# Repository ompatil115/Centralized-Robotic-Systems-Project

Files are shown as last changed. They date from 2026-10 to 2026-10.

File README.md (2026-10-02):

# Centralized Robotic Systems

Centralized Robotic Systems is a personal engineering project that explores how multiple robotic devices can be monitored and controlled through a unified, browser-based interface.

The project is being developed incrementally. Each phase introduces a new robotic device or system capability while building toward centralized coordination across devices with different hardware, functions, and levels of complexity.

## Project Status

| Phase | Device or Capability | Status |
|---|---|---|
| Phase 1 | Embedded robotic vehicle | Complete (V1 scope) |
| Phase 2 | Additional robotic device (TBD) | Concept exploration |
| Future | Unified multi-device interface | Planned |

At present, the repository contains the completed Phase 1 robotic vehicle. Multi-device coordination has not been implemented yet.

## Phase 1: Embedded Robotic Vehicle Control System

Phase 1 demonstrates end-to-end remote control and two-way data communication between a browser interface and physical robotic hardware.

The vehicle has three primary functions:

1. Controllable multicolor lighting.
2. Forward, reverse, left, and right movement.
3. Distance scanning across a 180-degree field of view.

A browser-based interface accessible from devices on the same local network sends commands to the vehicle and displays returned sensor data.

### System Architecture

The system is divided into three primary layers:

- **Browser interface:** Provides lighting, movement, and scanning controls and displays scan results.
- **Raspberry Pi backend:** Hosts the Python/Flask service, processes HTTP requests, manages system state, and communicates with the Arduino through USB serial.
- **Arduino firmware:** Performs low-level control of the motors, servo, ultrasonic sensor, and lighting hardware.

This separation keeps the microcontroller firmware focused on hardware control while assigning interface and coordination functions to the Raspberry Pi.

### Communication Flow

```text
Browser Interface
       |
     HTTP
       |
Raspberry Pi 5
Python / Flask
       |
   USB Serial
       |
 Arduino Uno
       |
Motors, Servo, Ultrasonic Sensor, and Lighting
```

See [`Robot-Car-V1/`](Robot-Car-V1/) for full build documentation, firmware, backend code, and media.

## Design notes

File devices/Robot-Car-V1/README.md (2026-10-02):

# Embedded Robotic Vehicle Control System (Robot Car V1)

A browser-controlled robotic vehicle built on a Raspberry Pi and Arduino, 
supporting remote-controlled movement, RGB lighting, and ultrasonic distance 
scanning over a local network. Built as a first full-stack embedded systems 
project, from protocol design through firmware, backend, and interface.

## Overview

- **Firmware (C++, Arduino Uno)** — motor, servo, and ultrasonic sensor control
- **Backend (Python/Flask, Raspberry Pi)** — serial-to-HTTP bridge, 
  multithreaded command handling, safety watchdog
- **Interface (HTML/CSS/JS)** — browser-based control panel: color picker, 
  directional movement pad, and a live scan visualization

See [`docs/architecture.md`](docs/architecture.md) for system design and 
[`docs/protocol.md`](docs/protocol.md) for the full serial command spec.

## Features

- Real-time RGB lighting control via a gradient slider
- Directional drive/turn control with variable-speed forward movement
- 180° ultrasonic distance scanning with live results display
- Thread-safe backend handling concurrent serial I/O and command locking
- Motor safety watchdog that halts output if control input stops

## Hardware

- Raspberry Pi 5 (headless, Linux)
- Arduino Uno R3
- DRV8833 dual motor driver
- 2x 6V DC motors
- SG90 micro servo
- HC-SR04 ultrasonic sensor
- RGB LED

## Setup

**Firmware**
1. Open `firmware/robot_control.ino` in the Arduino IDE
2. Install the `Servo` and `SR04` libraries
3. Upload to an Arduino Uno wired per the pin map in `docs/architecture.md`

**Backend**
```bash
cd backend
pip install -r requirements.txt
python3 app.py
```
Connect the Arduino to the Pi via USB, then visit `http://<pi-ip>:5000` 
from any device on the same network.

## Status

Version 1 is complete and functional: all three subsystems (light, move, 
scan) work end-to-end, browser to hardware and back. V1 ran against a 
hardware constraint — attaching the servo library consumes a timer the 
Uno needs for PWM on two pins, leaving too few PWM-capable pins for full 
RGB and full variable-speed control in both directions. See 
`docs/architecture.md` for the tradeoff and what V1 scoped out as a result.

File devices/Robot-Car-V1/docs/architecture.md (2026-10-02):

# System Architecture

Three layers, each responsible for a distinct part of the system:

**Browser (JavaScript)** — renders the interface (light slider, movement pad, 
scan button/chart), computes derived values (RGB from slider position, 
direction/intensity from pad position), and sends commands to the backend 
over HTTP.

**Backend (Python/Flask, on Raspberry Pi)** — mediates between browser and 
hardware. Translates HTTP requests into serial commands, and parses serial 
responses back into JSON for the browser. Runs three concurrent threads: 
the main Flask request handler, a background serial reader (continuously 
parsing scan data and watching for completion), and a watchdog that halts 
motor output if movement commands stop arriving.

**Firmware (C++, on Arduino Uno)** — executes hardware control: PWM for 
motors and lighting, servo positioning, ultrasonic distance sampling. Parses 
incoming serial commands and dispatches to the matching function.

Computation was deliberately kept off the Arduino where possible (color 
math, direction/intensity logic) to minimize firmware complexity, since the 
Uno also handles time-sensitive sensor timing and motor control.

## Data flow
Browser → HTTP → Flask → Serial → Arduino → (physical action, or serial 
response) → Flask (background thread) → JSON → Browser

## V1 Hardware Constraint: PWM Pin Availability

The Arduino Uno has six PWM-capable pins. Attaching the Servo library 
claims Timer1, which disables PWM on two of them, leaving four usable 
PWM pins. Full-scope control (variable-speed in all four directions, 
plus full RGB) requires seven. V1 scoped down accordingly:

- **Light:** blue channel omitted entirely (saves one PWM pin); red and 
  green retain full gradient control.
- **Move:** only forward drive retains true variable speed (one PWM pin, 
  shared across both motors); backward and turning are binary — any 
  nonzero input runs at max intensity, since those directions use the 
  non-PWM motor pins.

This is a scoping decision, not a bug. Planned Version 2 fix: add a PCA9685 
PWM driver board, which provides 16 additional PWM channels, removing 
this constraint entirely.

## Physical Build

V1 used LEGO for the chassis, a deliberate rapid-prototyping choice to 
validate the electrical and software architecture without investing time 
in a custom frame before the control system was proven. Despite the 
material, the chassis followed real mechanical reasoning: a modular 
design (motors, battery, sensor/servo, and "brain" as separable units) 
for easy disassembly during debugging, with the battery — the heaviest 
component — placed directly over the wheel modules to minimize torque 
load during turns. Phase 2 replaces this with a soldered, purpose-built 
frame.

## Media

- **Full system demo (browser control → robot response):** https://youtu.be/HuvUpwN8BuI
- **Modular design:** https://youtu.be/toOqbU9Gd-k
- **Modular design breakdown:** https://youtu.be/CyCH8XhwyrI
- **Physical build:** [`media/robot-photo.jpg`](media/robot-photo.jpg)
- **Schematic:** [`media/schematic.png`](media/schematic.png) 
  ([KiCad source](media/robot-car.kicad_sch))

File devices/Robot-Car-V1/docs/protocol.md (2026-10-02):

# Serial Command Protocol

Communication between the Flask backend and Arduino firmware uses plain-text 
commands over USB serial, one command per line, terminated with `\n`.

## Light
- `LIGHT:<r>,<g>,0` — sets red/green PWM values (0–255). Blue omitted in V1 
  due to PWM pin constraints.
- `LIGHT:0` — turns the light off.

## Move
- `DRIVE:<i>` — forward/backward, intensity -100 to 100. Forward has true 
  variable speed; backward is binary (any negative value = max intensity).
- `TURN:<i>` — left/right, intensity -100 to 100, binary (any nonzero value 
  = max intensity).
- `DRIVE:0` / `TURN:0` — stop, halts all motor output regardless of axis.

Move commands are sent continuously (10–20 Hz) while an input is active. A 
backend watchdog sends a stop command if updates stop arriving.

## Scan
- `SCAN` — triggers a 0–180° servo sweep with ultrasonic distance sampling.
- `SCAN_DATA:<angle>:<distance>` — one line per reading, sent by the Arduino 
  during the sweep (distance in cm, 0–400).
- `SCAN_DONE` — sent once the sweep completes; the backend returns all 
  collected readings to the browser as JSON.

Only one command type (Light, Move, Scan) executes at a time. The backend 
rejects Light/Move requests while a scan is in progress.

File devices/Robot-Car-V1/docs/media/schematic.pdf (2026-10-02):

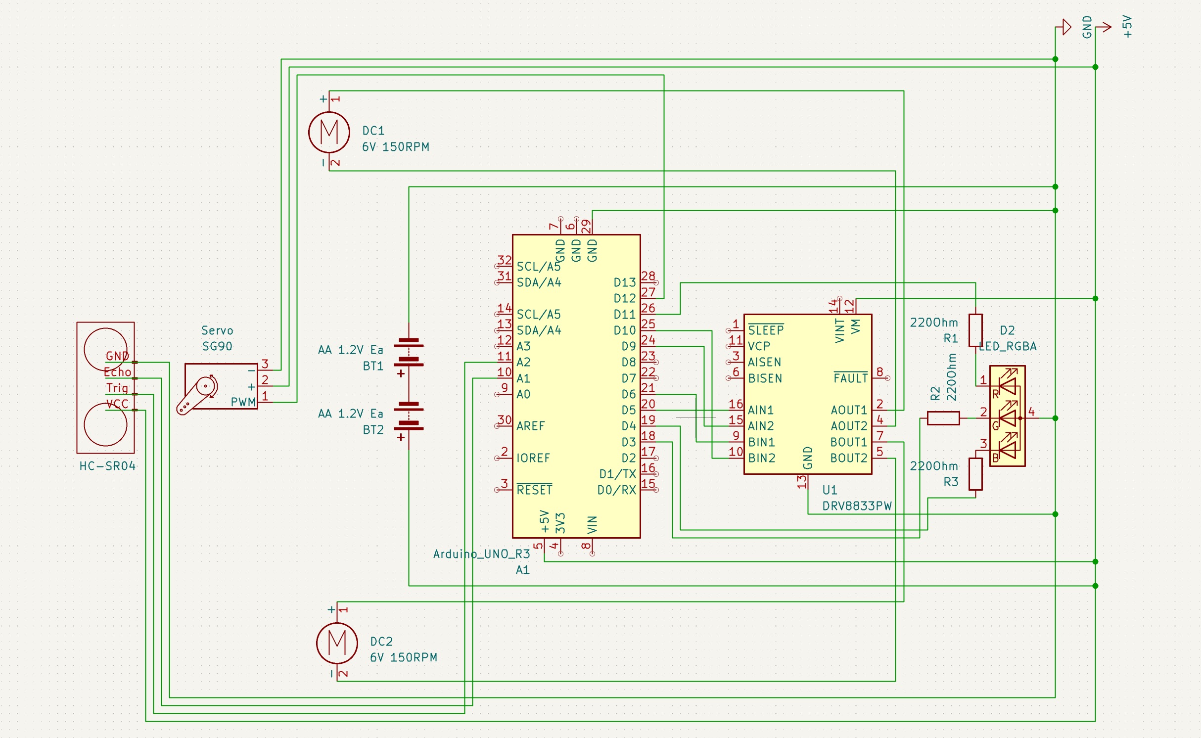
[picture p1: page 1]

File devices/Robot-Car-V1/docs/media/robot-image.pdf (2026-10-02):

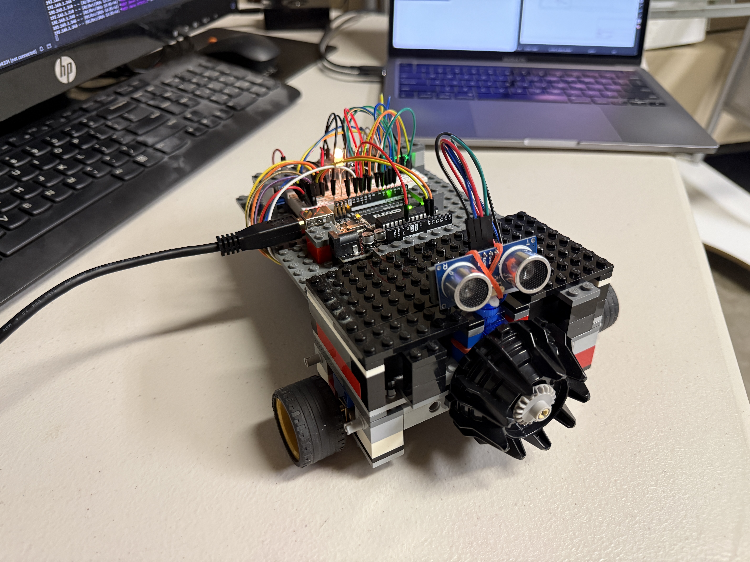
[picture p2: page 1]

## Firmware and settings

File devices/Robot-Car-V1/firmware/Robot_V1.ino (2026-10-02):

//  Robot V1 Code  //
//  Om Patil       //
//  2026-09-29     //

#include <Servo.h>
#include <SR04.h>

// ---------- Pin Definitions ----------
#define ENABLE 7
#define DIRA 5
#define DIRB 9
#define DIRC 6
#define DIRD 10
#define RED 11
#define GREEN 3
//#define BLUE 4
#define SERVO 12
#define TRIG_PIN A1
#define ECHO_PIN A0

Servo servo;
SR04 sr04(ECHO_PIN, TRIG_PIN);

void setup() {
  pinMode(ENABLE, OUTPUT);
  pinMode(DIRA, OUTPUT);
  pinMode(DIRB, OUTPUT);
  pinMode(DIRC, OUTPUT);
  pinMode(DIRD, OUTPUT);
  pinMode(RED, OUTPUT);
  pinMode(GREEN, OUTPUT);
  pinMode(TRIG_PIN, OUTPUT);
  pinMode(ECHO_PIN, INPUT);
  servo.attach(SERVO);
  digitalWrite(ENABLE, HIGH);
  Serial.begin(9600);
}

// ---------- Light ----------
void setLight(int r, int g) {
  analogWrite(RED, r);
  analogWrite(GREEN, g);
}

void lightOff() {
  setLight(0, 0);
}

// ---------- Move ----------
void allStop() {
  digitalWrite(DIRA, LOW);
  digitalWrite(DIRB, LOW);
  digitalWrite(DIRC, LOW);
  digitalWrite(DIRD, LOW);
}

void driveForward(int i) {
  int speed = map(i, 1, 100, 69, 255);
  analogWrite(DIRA, speed);
  digitalWrite(DIRB, LOW);
  analogWrite(DIRC, speed);
  digitalWrite(DIRD, LOW);
}

void driveBackward() {
  digitalWrite(DIRA, LOW);
  digitalWrite(DIRB, HIGH);
  digitalWrite(DIRC, LOW);
  digitalWrite(DIRD, HIGH);
}

void turnLeft() {
  digitalWrite(DIRA, LOW);
  digitalWrite(DIRB, HIGH);
  digitalWrite(DIRC, HIGH);
  digitalWrite(DIRD, LOW);
}

void turnRight() {
  digitalWrite(DIRA, HIGH);
  digitalWrite(DIRB, LOW);
  digitalWrite(DIRC, LOW);
  digitalWrite(DIRD, HIGH);
}

void drive(int i) {
  if (i > 0) driveForward(i);
  else if (i < 0) driveBackward();
  else allStop();
}

void turn(int i) {
  if (i > 0) turnRight();
  else if (i < 0) turnLeft();
  else allStop();
}

// ---------- Scan ----------
void sweep(int angle) {
  servo.write(angle);
}

long readDistance() {
  return sr04.Distance();
}

void scan() {
  for (int angle = 0; angle <= 180; angle += 10) {
    sweep(angle);
    delay(300);
    long distance = readDistance();
    Serial.print("SCAN_DATA:");
    Serial.print(angle);
    Serial.print(":");
    Serial.println(distance);
  }
  sweep(90);
  Serial.println("SCAN_DONE");
}

void loop() {
  if (Serial.available() > 0) {
    String cmd = Serial.readStringUntil('\n');
    cmd.trim();

    if (cmd.startsWith("LIGHT:")) {
      String rest = cmd.substring(6);

      if (rest == "0") {
        lightOff();
      } else {
        int firstComma = rest.indexOf(',');
        int secondComma = rest.indexOf(',', firstComma + 1);

        int r = rest.substring(0, firstComma).toInt();
        int g = rest.substring(firstComma + 1, secondComma).toInt();

        setLight(r, g);
      }
    }

    else if (cmd.startsWith("DRIVE:")) {
      int i = cmd.substring(6).toInt();
      drive(i);
    }

    else if (cmd.startsWith("TURN:")) {
      int i = cmd.substring(5).toInt();
      turn(i);
    }

    else if (cmd == "SCAN") {
      scan();
    }
  }
}

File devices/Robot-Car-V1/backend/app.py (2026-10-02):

from flask import Flask, request, render_template
import serial
import time
import threading

app = Flask(__name__)

arduino = serial.Serial('/dev/ttyACM0', 9600, timeout=1)
time.sleep(2)

scan_data = []
scan_done = threading.Event()
data_lock = threading.Lock()
scan_in_progress = False
last_move_time = time.time()


def read_serial():
    while True:
        line = arduino.readline().decode().strip()
        if line.startswith("SCAN_DATA:"):
            parts = line.split(":")
            angle = int(parts[1])
            distance = int(parts[2])
            with data_lock:
                scan_data.append((angle, distance))
        elif line == "SCAN_DONE":
            scan_done.set()


def watchdog():
    already_stopped = False
    while True:
        time.sleep(0.1)
        if not scan_in_progress and time.time() - last_move_time > 0.5:
            if not already_stopped:
                arduino.write(b"DRIVE:0\n")
                already_stopped = True
        else:
            already_stopped = False


@app.route('/')
def index():
    return render_template('index.html')


@app.route('/light', methods=['POST'])
def light():
    if scan_in_progress:
        return "", 409
    r = request.form['r']
    g = request.form['g']
    if r == '0' and g == '0':
        arduino.write(b"LIGHT:0\n")
    else:
        arduino.write(f"LIGHT:{r},{g},0\n".encode())
    return "", 204


@app.route('/move', methods=['POST'])
def move():
    global last_move_time
    if scan_in_progress:
        return "", 409
    data = request.json
    move_type = data['type']
    i = data['value']
    arduino.write(f"{move_type}:{i}\n".encode())
    last_move_time = time.time()
    return "", 204


@app.route('/scan', methods=['POST'])
def scan():
    global scan_in_progress
    scan_in_progress = True
    scan_data.clear()
    scan_done.clear()
    arduino.write(b"SCAN\n")
    scan_done.wait()
    with data_lock:
        result = scan_data.copy()
    scan_in_progress = False
    return {"data": result}


threading.Thread(target=read_serial, daemon=True).start()
threading.Thread(target=watchdog, daemon=True).start()

if __name__ == '__main__':
    app.run(host='0.0.0.0', port=5000)

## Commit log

2026-10-02 Robot Car V1
    This phase develops a remotely operated robotic vehicle with three primary objectives:
    1. Provide controllable multicolor lighting using an RGB LED system.
    2. Drive forward and backward while supporting left and right turns at variable speeds.
    3. Scan for objects across a 180-degree field of view and report their measured distances.
    The purpose of this version is to demonstrate end-to-end remote control and two-way data communication. A browser-based interface accessible from devices on the same network sends control commands to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
    The system connects a browser interface, Raspberry Pi backend, and Arduino-based hardware controller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
2026-10-02 Create Robot Car V1 Schematic
2026-10-02 Create schematic
2026-10-02 Rename Robot Car V1 Schematic.pdf to schematic.pdf
